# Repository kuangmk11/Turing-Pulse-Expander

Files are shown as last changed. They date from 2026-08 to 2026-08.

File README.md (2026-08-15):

# Turing Pulse Expander — archive

> **This repository is an archive.** The finished work has moved out into its own
> repositories; what remains here is upstream material and the studies that were
> superseded along the way.

| Live work | |
|---|---|
| **[Doubleplus_Pulses](https://github.com/kuangmk11/Doubleplus_Pulses)** | **Pulses Plus** — the built and tested hardware. KiCad schematic, PCB, panel v4, BOM, gerbers, and the full design write-up. CC BY-NC-SA 4.0. |
| **[Doubleplus_Pulses_VCV](https://github.com/kuangmk11/Doubleplus_Pulses_VCV)** | The VCV Rack 2 port of the same module. GPL-3.0-or-later. |

Both were extracted with `git subtree split`, so their commit history came with
them. Their files remain in this repository's history too, up to the commit that
removed them — nothing was rewritten here.

---

## What Pulses Plus is

A performance-oriented gate router for the Music Thing Turing Machine: eight pulse
channels, each switchable to one of two merge buses or off, with each bus computing
the OR or the AND of whatever is routed to it, chosen live from the panel. It
generalises the stock Pulses expander's four hard-wired AND outputs into any subset
of the eight bits, OR'd or AND'd, by hand.

See [Doubleplus_Pulses](https://github.com/kuangmk11/Doubleplus_Pulses) for the
design and the write-up.

---

## What's left here

### Upstream: Rev 2 Turing Pulse Expander

This repository is a fork of
[TomWhitwell/Turing-Pulse-Expander](https://github.com/TomWhitwell/Turing-Pulse-Expander),
and keeps that link deliberately — it is the right home for Tom Whitwell's files.

- `Hardware/pulses_rev2.brd`, `Hardware/pulses_rev2.sch` — the original Eagle design
- `Collateral/` — his gerbers, panel artwork and schematic PDF

The Rev 2 expander is a slightly updated Turing Machine Pulse Expander with more
outputs — SMD, but still an easy build. Its BOM:

- 1 × 4081 Quad AND Gate, SO14 package
- 11 × 3 mm LEDs
- 11 × 1k resistors, 1206
- 11 × 2k resistors, 1206 (LED protection — change the value for high-intensity LEDs)
- 11 × [Thonkiconn](https://www.thonk.co.uk/shop/thonkiconn-3-5mm-jack-sockets-x50/) sockets
- 1 × 16-pin header 2×8 (e.g. Mouser 649-67997-216HLF)
- 1 × ribbon cable

### Dead ends and studies

- `Docs/build_*.py`, `kfp.py`, `ksym.py`, `panel_geom.py`, `patch_footprints.py` —
  the generator scripts that built the earlier `pulses_plus` board from source.
  The finished module took a different route: it carries a single, much smaller
  `tools/build_panel.py` that regenerates only panel artwork from the v1 panel.
- `Docs/panel/` — two early panel layout studies (`v1-two-column-grid.html`,
  `v2-zigzag.html`) and the notes comparing them. The zig-zag won and became the
  shipped panel.
- `Hardware/pulses_plus/` — the superseded full-size design that preceded the
  sub-miniature-toggle version. **Present on disk but never committed**; it is
  gitignored and always has been, so it does not exist in this repository's
  history and will not appear in a fresh clone.
- Assorted scratch material at the repository root (`Chat.txt`, `path30.svg`,
  panel artwork exports) — likewise gitignored, on disk only.

---

## Licence

**Tom Whitwell's Rev 2 expander** — `Hardware/pulses_rev2.brd`, `Hardware/pulses_rev2.sch`
and `Collateral/` — is his, inherited by forking
[TomWhitwell/Turing-Pulse-Expander](https://github.com/TomWhitwell/Turing-Pulse-Expander).
Nothing here grants rights over it. For context, the parent
[Turing Machine](https://github.com/TomWhitwell/TuringMachine) project's README states
[CC-BY-SA 3.0](https://creativecommons.org/licenses/by-sa/3.0/), but that is not
stated in the expander repository itself.

**The Pulses Plus studies** in `Docs/` are Missing Mile Modular's, under
[CC BY-NC-SA 4.0](https://creativecommons.org/licenses/by-nc-sa/4.0/) — the same
terms as the finished hardware.

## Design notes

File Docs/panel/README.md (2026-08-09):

# Panel layout iterations — Pulses Plus

Open the HTML files in a browser. Both draw the panel **to scale** (1 HP = 5.08 mm, 3U = 128.5 mm).

| File | Layout | Outcome |
|---|---|---|
| `v1-two-column-grid.html` | Toggles in a 2 × 4 grid, LEDs outboard | Superseded. Needed 8–12 HP. |
| `v2-zigzag.html` | Toggles alternating left/right of a centred LED column | **Current.** Fits 6 HP. |

## What each iteration established

**v1** proved the constraint that shapes everything else: a 3U panel has ~110 mm of usable height,
and a single column of ten toggles plus three jacks needs ~160 mm. There is no single-column version
of this module — the channels have to be split across two columns somehow.

**v2** found the better way to split them. Staggering the toggles left and right of a centred LED
column means vertically adjacent toggles are never on the same side, so **row pitch no longer has to
clear a toggle nut**. That decoupling is what buys 6 HP: same-side toggles end up 17.25 mm apart —
more finger room than v1's 10 HP grid had — in half the width.

With the bus outputs moved to the bottom (jacks at the very bottom, vertical-throw mode toggles
above them, bus LEDs above those), the channel zigzag stretches to fill the panel at an 8.625 mm row
pitch. That pitch isn't chosen — it's back-solved from landing the EXT jack one full zigzag step
below channel 8 while still clearing the bus LEDs.

Each channel LED rides 2.5 mm above its toggle's row with the channel number silkscreened directly
beneath it, which is what makes the alternation readable at a glance.

## The remaining constraint is horizontal, and the nut decides it

Switch selected: **Adam Tech SW-T2-4X-E-A2-MA2** — DPDT ON-OFF-ON, M6 × 0.75 bushing, PCB vertical.
DPDT is an electrical requirement, not a preference; a single-pole switch leaks the AND bus into the
OR bus through the unselected throw (see the topology note in
[`../pulses-plus-design.md`](../pulses-plus-design.md)).

That's a *miniature* bushing, not sub-miniature, so at 6 HP there is only **1.6 mm of panel between
each toggle nut and its LED hole** — buildable, but only with bare 3 mm LEDs in bare holes, no bezels
or holders. Behind the panel, the 13.2 mm body against a 14.5 mm column pitch leaves 1.3 mm between
adjacent switch bodies. Tight, but it clears.

**Panel gets the ø6.00 mm bushing hole only — no anti-rotation key hole.** Adam Tech's recommended
cut-out puts a ø2.40 mm key hole 6.40 mm from the bushing centre, which would overlap the channel
LED hole outright. The six solder pins prevent rotation once the switch is PCB-mounted, so the key
hole is unnecessary. Don't copy the datasheet cut-out into the panel DXF.

**The nut turned out not to be a gate — 6 HP works.** Worst plausible M6 toggle nut (11 mm across
corners) still clears the LED hole by 0.52 mm; a typical 9.2 mm nut clears by 1.42 mm. It never
overlaps. So the nut only decides how tight the panel *looks*, and whether an LED bezel is possible
(it isn't). 6 HP vs 8 HP is now a rack-space call, not an engineering one — 8 HP takes that gap to
6.3 mm and leaves room for real legends.

## The panel as a PCB

`../build_panel.py` generates the panel as a standalone board — holes and silkscreen only, no
components — to `../../Hardware/pulses_plus/pulses_plus_panel_{6,8}hp.kicad_pcb`. Switches and jacks
mount on the main board behind and their own nuts hold the panel on. Artwork is on F.SilkS with the
F side facing the player.

Toggle columns are pinned to the panel **edge** rather than the centreline, so extra HP goes into the
toggle-to-LED gap — the only place it's needed.

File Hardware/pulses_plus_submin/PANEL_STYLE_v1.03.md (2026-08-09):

# Front panel style

**Version 1.03.**

House style for my module front panels — what marks go on them, what each one means, and
where it sits. It is a drawing spec, not a program: a panel is in the style if it satisfies
the rules below, whether it was generated or drawn by hand.

The look is borrowed from RYO's *Altered States* (`reference.jpg`) and is deliberately
PCB-native: single-weight plotter lettering, connections routed the way a trace is routed,
and dots where a silkscreen would have vias. Printed as white silkscreen on black
soldermask.

The rules were fitted to a set of eleven generated Kassutronics panels. That is where the
numbers come from, and why some are stated to the hundredth of a millimetre — they were
measured off production artwork, not chosen.

## Two ways to draw one

**Generated.** One `<stem>.layout.json` per panel says what its controls are and how they
relate; every mark comes from a single style library, so changing a number there changes
every panel at once.

```sh
tools/build_styled_panels.sh            # every finished layout
tools/build_styled_panels.sh Slope      # just the ones whose path matches
```

Outputs land beside each source as `<stem>.styled.{panel.json,kicad_pcb,svg}`, leaving the
PDF-derived conversions untouched.

**Drawn.** A hand-written SVG at 1:1, one user unit = 1 mm — `docs/v3-panel.svg` in this
repo is one. Nothing below needs a generator; the tokens are just numbers.

Where a rule is easier to state as tool behaviour ("the composer refuses to write if…"), it
is stated here as the rule being enforced. A generator should enforce it. A hand drawing has
to be checked.

## The one rule that is not negotiable

**Control hole positions are inherited, never computed.**

A panel serving a board that already exists — a port of someone else's module, or a revision
like this adder's v3 — takes its hole positions from that board and may not move them. A
panel whose holes move stops fitting its main board. v3 reassigns hole *diameters* between
6 mm jack and 5 mm toggle and keeps all sixteen positions from the built v2.2 panel.

On a genuinely new board the positions are fitted once, when the board is laid out, and are
inherited from then on.

Either way, **every hole is accounted for**, so a jack cannot silently vanish because a
layout forgot it.

Mounting holes are the exception: they meet the rails, not the module's own board, so they
are regenerated (below).

## Tokens

Every value is one number in one place. A generator holds them together; a hand drawing
copies them from here.

| | value | |
|---|---|---|
| `LINE_W` / `RULE_W` | 0.25 / 0.20 mm | wires, brackets, rings / centre divider |
| `LABEL_SIZE` / `PITCH_LABEL` | 2.0 / 2.2 mm | control labels |
| `SMALL_SIZE` / `PITCH_SMALL` | 1.6 / 1.7 mm | crowded rows, notes, bracket labels |
| `TITLE_SIZE` / `PITCH_TITLE` | 3.2 / 3.4 mm | module name |
| `LOGO_SIZE` / `PITCH_LOGO` | 1.3 / 1.45 mm | wordmark |
| `TRAVEL_DOT_D` / `TRAVEL_END_D` | 0.9 / 1.4 mm | knob travel marks |
| `DOT_D` | 0.6 mm | star-field, when used at all |
| `RING_GAP` | 1.2 mm | output ring stands off the hole edge |
| `EDGE_MARGIN` | 0.6 mm | no silkscreen closer than this to the cut |

**Tracking.** The reference's lettering is monospaced and widely tracked; stroke fonts
(Newstroke, and most plotter faces) are proportional, and KiCad has no letter-spacing
setting. So text is set **one character at a time** on a fixed pitch, each centred in its
own cell. Everything is uppercase.

## Marks and what they mean

**Knob travel — a dotted arc.** Eleven dots every 30°, at every position except +90°; the
gap at the bottom is where the label goes and the two dots either side of it, at +120° and
+60°, are the ends of travel and are drawn heavier. These positions are not invented: they
are measured off the starbursts on the ASR, both Attenumix panels and the Avalanche VCO,
which all draw the same 300° pot. The radius sits inside the band that artwork occupies —
3.75 to 8.06 mm on a 7.5 mm pot — so the marks stay visible with a knob fitted.

```
        ·  ·  ·               11 dots, r = hole_r + 3.45
      ·         ·
    ·     (O)     ·           hole
      ·         ·
     ●           ●            heavy: ends of travel, +120 / +60
          FOLD                the 30 deg gap at +90
```

- a **small** knob pulls the radius in for tightly spaced rows (Slope's Shape/Sustain sit on
  13.3 mm centres);
- a **big** knob draws **two** concentric rings, for an oversized main knob whose starburst
  runs out to 18.5 mm rather than 8.5 — the 3340 and KS-20 Frequency, the Ladder Filter, the
  Wavefolder's Fold;
- **bipolar** adds a heavier dot at 12 o'clock for the centre detent, and sets `-` / `+`
  outside the travel ends;
- **named ends** do the same with words, for the KS-20's `LP` / `HP` Mode.

**A ring means signal leaves here.** Every jack is an input or an output, and an output
draws the ring. Keeping it the only closed circle on a panel is what lets direction read at
a glance — which is also why nothing else may be a closed circle.

**A bracket groups one direction only.** It says *these belong together*, so enclosing an
input and an output in one misstates the signal flow. A bracket that mixes directions is an
error, not a judgement call. Labels sit in gaps in the bracket's own top edge. An output row
inside a bracket does not also get rings — the bracket already says it.

**An outline groups by function, not direction.** A plain rounded box at the lighter rule
weight, drawn round everything belonging to one section — the Quantizer's two channels, each
of which necessarily has both an input and an output, so the bracket's one-direction rule
does not apply. Where a bracket labels a row in its own top edge and must not mix
directions, an outline just says *this lot is one thing*.

**A span is one shared label** over a bar covering the controls it names, with a tick turning
down at each end — the 3340's two V/Oct inputs get one word, not the same word twice.

**A wire is a connection**, routed with one knee using only 0°, 90° and 45° segments,
stopping short of what it joins and breaking around any label it passes under. Routing does
**not** avoid obstacles: check that a wire does not cross a control, or drop it.

## Layout

**A name goes below the thing it names.** Every jack, every LED, every pot, every switch —
one rule, no exceptions, measured from whatever is drawn around the hole (a pot's travel
ring, an output's ring) and not from the hole itself. A panel where some names sit above
and some below makes the reader work out which each time.

**A mark that means a position goes where that position is.** Travel dots ring the pot,
`+` and `−` straddle a toggle, selector values stack beside the throws they select. These
are not names and the rule above does not apply to them — a `+` under a switch is wrong
however consistent it looks.

That leaves the case where a switch needs a name *and* position marks. The name takes the
baseline of the topmost position mark, off to one side of it. It must not sit directly
outboard of a `+` on the same baseline, or the two read as one word — `+OCTAVE`.

Three things adjust themselves and should not be fought:

- a row whose labels would collide, or would need shoving back inside the board, drops to the
  small size **as a whole row**;
- every label in a row is snapped to one baseline, so a ringed output does not sit 1.2 mm
  below its plain neighbours;
- the title shrinks to fit the clear span between the mounting slots.

When a row still needs help, in the order to reach for it: the small size, a larger label
gap, the label moved to a named direction, the label placed at an explicit `[x, y]`. An
explicit title height and size exist for panels where a control near the top leaves only
~2 mm of clear band.

## Mounting

Regenerated to one rule, as 6.4 × 3.2 mm obround slots milled on Edge.Cuts — horizontal, so
a module can slide ±1.6 mm to meet its neighbours.

| | |
|---|---|
| vertical | centre 3.0 mm from the top and bottom edges |
| horizontal | centre 7.5 mm in from the edge; the opposite column steps out by N × 5.08 mm |
| **> 6 HP** | both columns, 4 slots — 8 HP at 7.5 / 32.9, 10 HP at 7.5 / 43.06 |
| **≤ 6 HP** | one slot top and bottom on **opposite corners**, top right and bottom left. One screw per rail is enough at that width, and diagonal placement stops the module pivoting. |

The 7.5 mm inset is the datum and the grid steps out from it, so the far margin lands at
7.26–7.44 rather than exactly 7.5. That is the way round that matters: the grid is what the
rail is drilled to.

Where the panel is inherited (above), its existing mounting holes win — a v2.2-era panel with
round Ø3.2 holes keeps them.

## The wordmark

**The mark names who designed the module.**

| the design is | the panel says |
|---|---|
| mine, original | `MISSING MILE MODULAR` — `MMM` where the width does not allow it |
| a port or revision of someone else's | that maker's name — `KASSUTRONICS`, `KT` on 4 HP |
| this precision adder | `508`, which is what the built v2.2 panel carries, kept for continuity |

Whatever the word, it is letterspaced inside a plain two-lead component frame — the same
schematic-fragment idea as RYO's, a different part. It sits at `height − 7.0`, above the
mounting line, because a 6.4 mm slot leaves only 17.8 mm between the bottom pair and a full
wordmark needs 19.0. At 4 HP the bottom margin has only ~7 mm of clear width, which is what
the short forms are for.

## The back of the panel

The front says who designed the module in three letters. The back says it in full, and
says what may be done with the design — it is the one surface with room, and nothing on
it competes with the artwork.

Two things go there, both on `B.SilkS`, uppercase and letterspaced like everything else,
at `SMALL_SIZE` or just under:

| | |
|---|---|
| credit | `DESIGNED BY MISSING MILE MODULAR <year>` — the year the artwork was cut, not the year the circuit was designed |
| licence | the short form alone, e.g. `CC-BY-SA`. No URL: it will not be read off the back of a module, and it costs a line |

Wrap the credit rather than shrink it. Below about 1.2 mm the strokes start to fill in on
black soldermask, so a long name becomes two lines at the small size, never one line at a
size chosen to fit.

**Placement is whatever the holes leave.** Control holes go clean through, so the back has
no artwork of its own to work around and no keepouts but the holes themselves. Find the
clear bands between hole rows and set the type in those; a band needs the line height plus
`EDGE_MARGIN` top and bottom. There is no fixed position, because no two panels leave the
same gaps.

**Back text is emitted right-to-left.** KiCad mirrors each glyph about its own anchor, so
a run of cells laid out left-to-right in board coordinates reads backwards once the board
is turned over. Since the tracking rule already sets every character in its own cell, the
fix is to reverse the cell order — the string is unchanged, the cells are dealt out from
the right. A generator does this; a hand drawing has to be checked against a mirrored
render, not against the editor.

## Screw holes

3.4 mm holes fix the board behind the panel. They are drilled and then ignored: they need no
layout entry, take no label and get no marks. Mounting slots are treated the same way.

## The star-field

Off. The reference's scatter reads as texture because it covers a whole panel edge to edge;
here, once the keepouts around holes, wires, brackets and type have taken their share, there
is nothing left but orphans — measured, 15 of 17 survivors on Slope had no near neighbour,
and the ASR had none at all. An orphan dot reads as fab dirt. The travel rings already carry
the polar-dot language.

It stays available, and a panel that turns out to have real open space can opt back in.

## Per-module cases

Rules that exist for one panel and are recorded so they are not mistaken for house style.

**The Kassutronics Quantizer's glyphs.** Its shift layer is iconographic, and those icons are
what its user manual teaches, so they are redrawn rather than replaced with words — twelve of
them, each built in a local box running -1..1 from the same strokes and arcs as everything
else and scaled on placement:

| button | glyph | function |
|---|---|---|
| 0 | `gate_length` | gate length — a crotchet and a minim, a short note and a long one |
| 1 | `rotate` | rotate menu |
| 2 / 3 | `transpose_both` / `transpose_one` | transpose |
| 4 / 5 | `offset_both` / `offset_one` | offset |
| 6 | `keyboard` | keyboard mode |
| 7 | `legato` | legato — two crotchets under a slur |
| 8 | `gear` | settings |
| 9 | `tau` | gate length |
| 10 / 11 | `cv_a` / `cv_b` | CV A / CV B menus |

The "both channels" glyphs carry two marks where the "one channel" ones carry one — the
distinction the original draws, and the one the manual describes. `tau` is drawn rather than
set, so it cannot depend on the stroke font carrying Greek.

**The keyboard ring inverts.** The original fills the five *black* keys as wedges on a white
panel. Straight onto black soldermask that reading breaks, so the seven **white** keys are
filled instead and the black keys are left as bare panel — same keyboard, same contrast,
opposite ink. Adjacent white keys (E–F, B–C) merge into one shape, as on a real keyboard.
Each wedge subtracts its own scale button's hole with clearance rather than printing over it.
The numbers moved outside the keyboard ring to make room, and **3 and 9 are omitted** — they
sit dead on the panel edges, exactly as on the original.

**Pulses Plus, and what an 8 HP panel of nothing but toggles forces.**

*The title wraps.* `DOUBLEPLUS++PULSES` is eighteen characters, which at `PITCH_TITLE`
wants 61 mm on a 40 mm panel. Shrinking it to fit puts the title at label size, where it
stops reading as a title at all. It breaks to two lines at the full `TITLE_SIZE` instead,
centred in the band between the top mounting holes and the first LED. Prefer two full-size
lines to one shrunken one whenever the clear band is tall enough.

*The bus indicator LEDs take no label.* Each bus is a column — indicator, mode switch,
output jack, in line — and the jack at the foot of the column is labelled `A` or `B`. A
letter on the LED as well would print the same word twice in 25 mm. This is a real
exception to "every LED gets a name", allowed only because the column reads as one thing
and the name is directly below it.

*`AND` / `MUTE` / `OR` is one stack between two switches.* Both mode switches carry the
same three positions, and the centre position cannot be marked where it is — that is the
hole. So the three words sit in the centre column, on the switches' own baselines, serving
both. Position marks normally go beside the control they belong to; here they go between
two identical controls, which is the only reading that does not double them.

*The throw marks do not.* All eight routing toggles throw on the X axis and are wired
identically, so `A`/`B` could have been said once. It is said on every switch, because it
is a position mark and not a name: the panel has to answer "which way is bus A" at the
switch the hand is on, not at the top of the column.

## Checking a panel

For a generated panel, start from a stub with every hole classified by diameter and each
label `TODO`; the build skips any layout still containing `TODO`.

```sh
python3 tools/panel_compose.py --stub documentation/Foo/Foo.panel.json
```

Then, in this order, however the panel was made:

1. **every control matched and every hole accounted for** — no unmatched control, no
   unaccounted hole;
2. **hole positions identical to the board's.** Compare against the drill file, not against
   the last drawing;
3. **no collisions.** For a KiCad panel, `kicad-cli pcb drc` reports **zero** violations —
   not "warnings only", since the keepouts are under our control and anything surviving is
   real. For a drawn panel, print at 100%, check the sheet measures what the drawing claims,
   and check clearance on anything unproven by an existing build;
4. **rasterise it and look at it.**

## Versioning

**Any change to this document increments the version by one hundredth** — v1.02 → v1.03 →
v1.04, and so on. There is no distinction between a typo and a new rule; every edit is a
bump.

Two things move together, and a change that touches only one of them is incomplete:

1. the version line at the top of this file;
2. the filename — `PANEL_STYLE_v1.03.md` → `PANEL_STYLE_v1.04.md`. Rename with `git mv` so
   the history follows the file.

Then update anything pointing at the old filename (`README.md`).

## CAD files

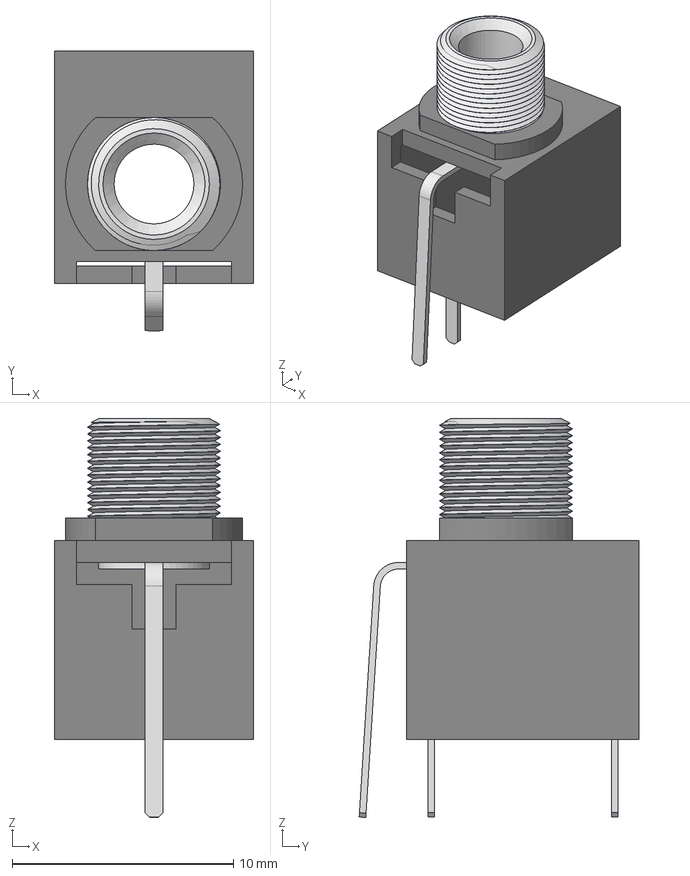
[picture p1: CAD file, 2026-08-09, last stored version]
Hardware/pulses_plus_submin/3d/PJ301M-12 Thonkiconn v0.2.stp
9.00 x 12.6 x 18.0 mm

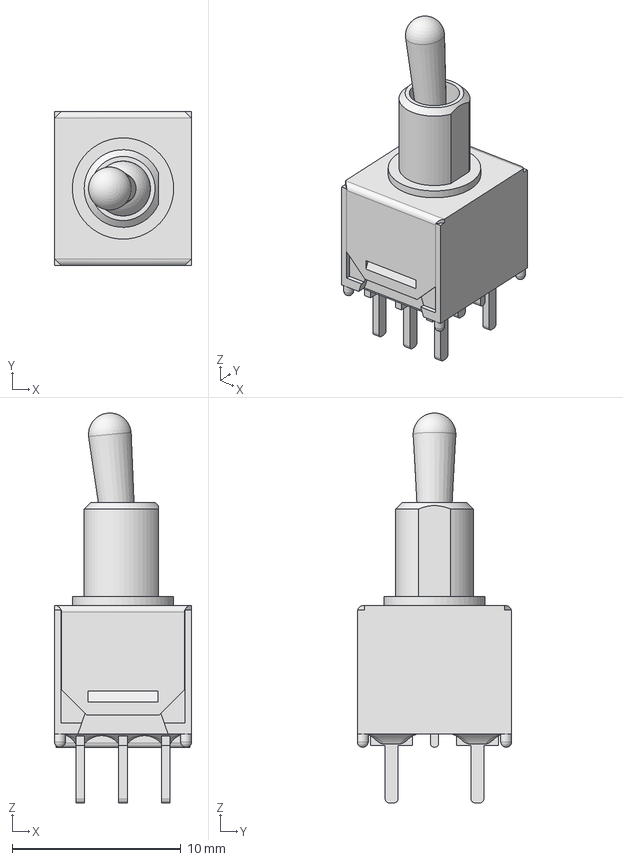
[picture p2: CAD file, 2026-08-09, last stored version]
Hardware/pulses_plus_submin/3d/200MDPxT2B1M2xE.stp
8.13 x 9.14 x 23.1 mm

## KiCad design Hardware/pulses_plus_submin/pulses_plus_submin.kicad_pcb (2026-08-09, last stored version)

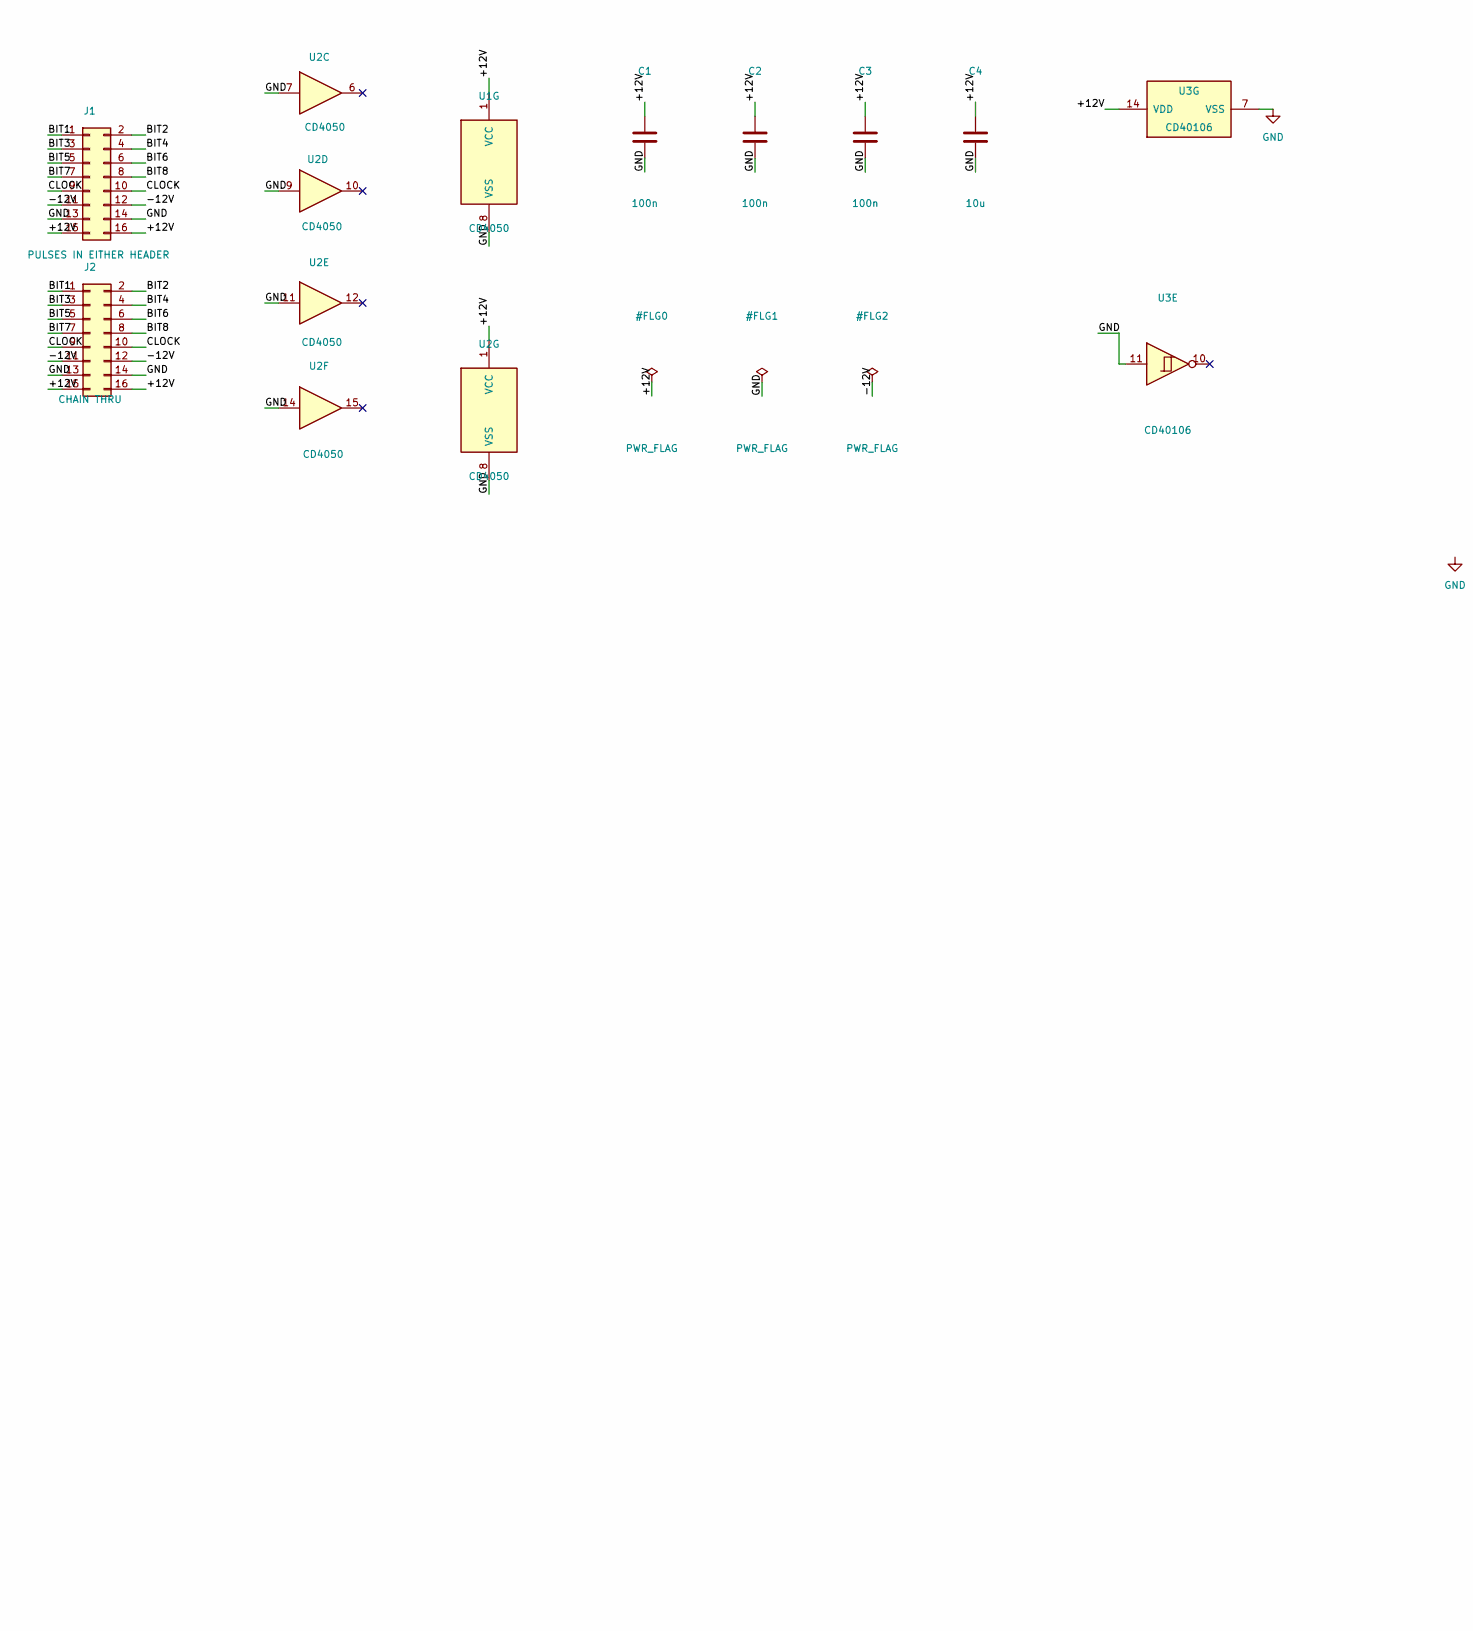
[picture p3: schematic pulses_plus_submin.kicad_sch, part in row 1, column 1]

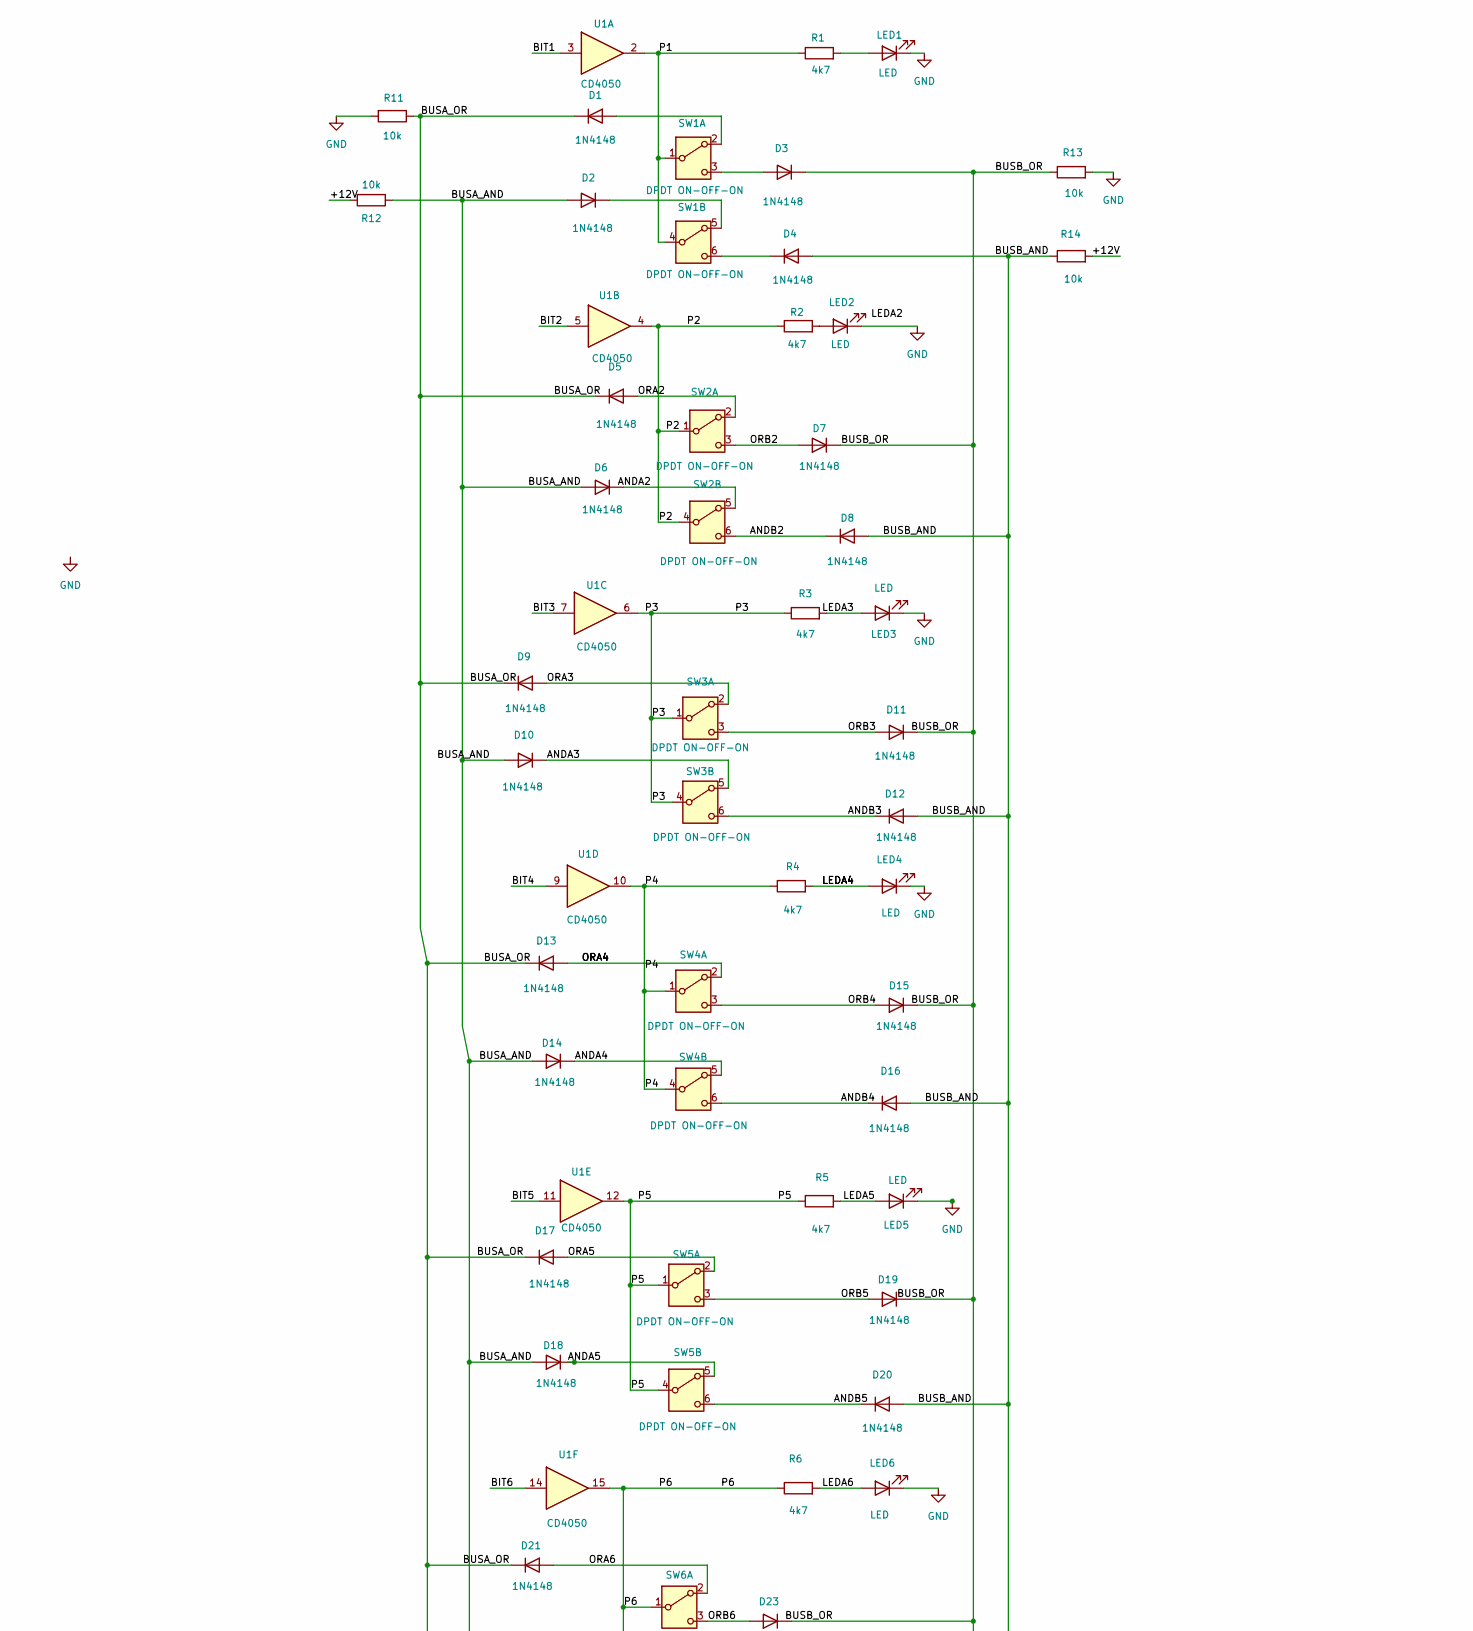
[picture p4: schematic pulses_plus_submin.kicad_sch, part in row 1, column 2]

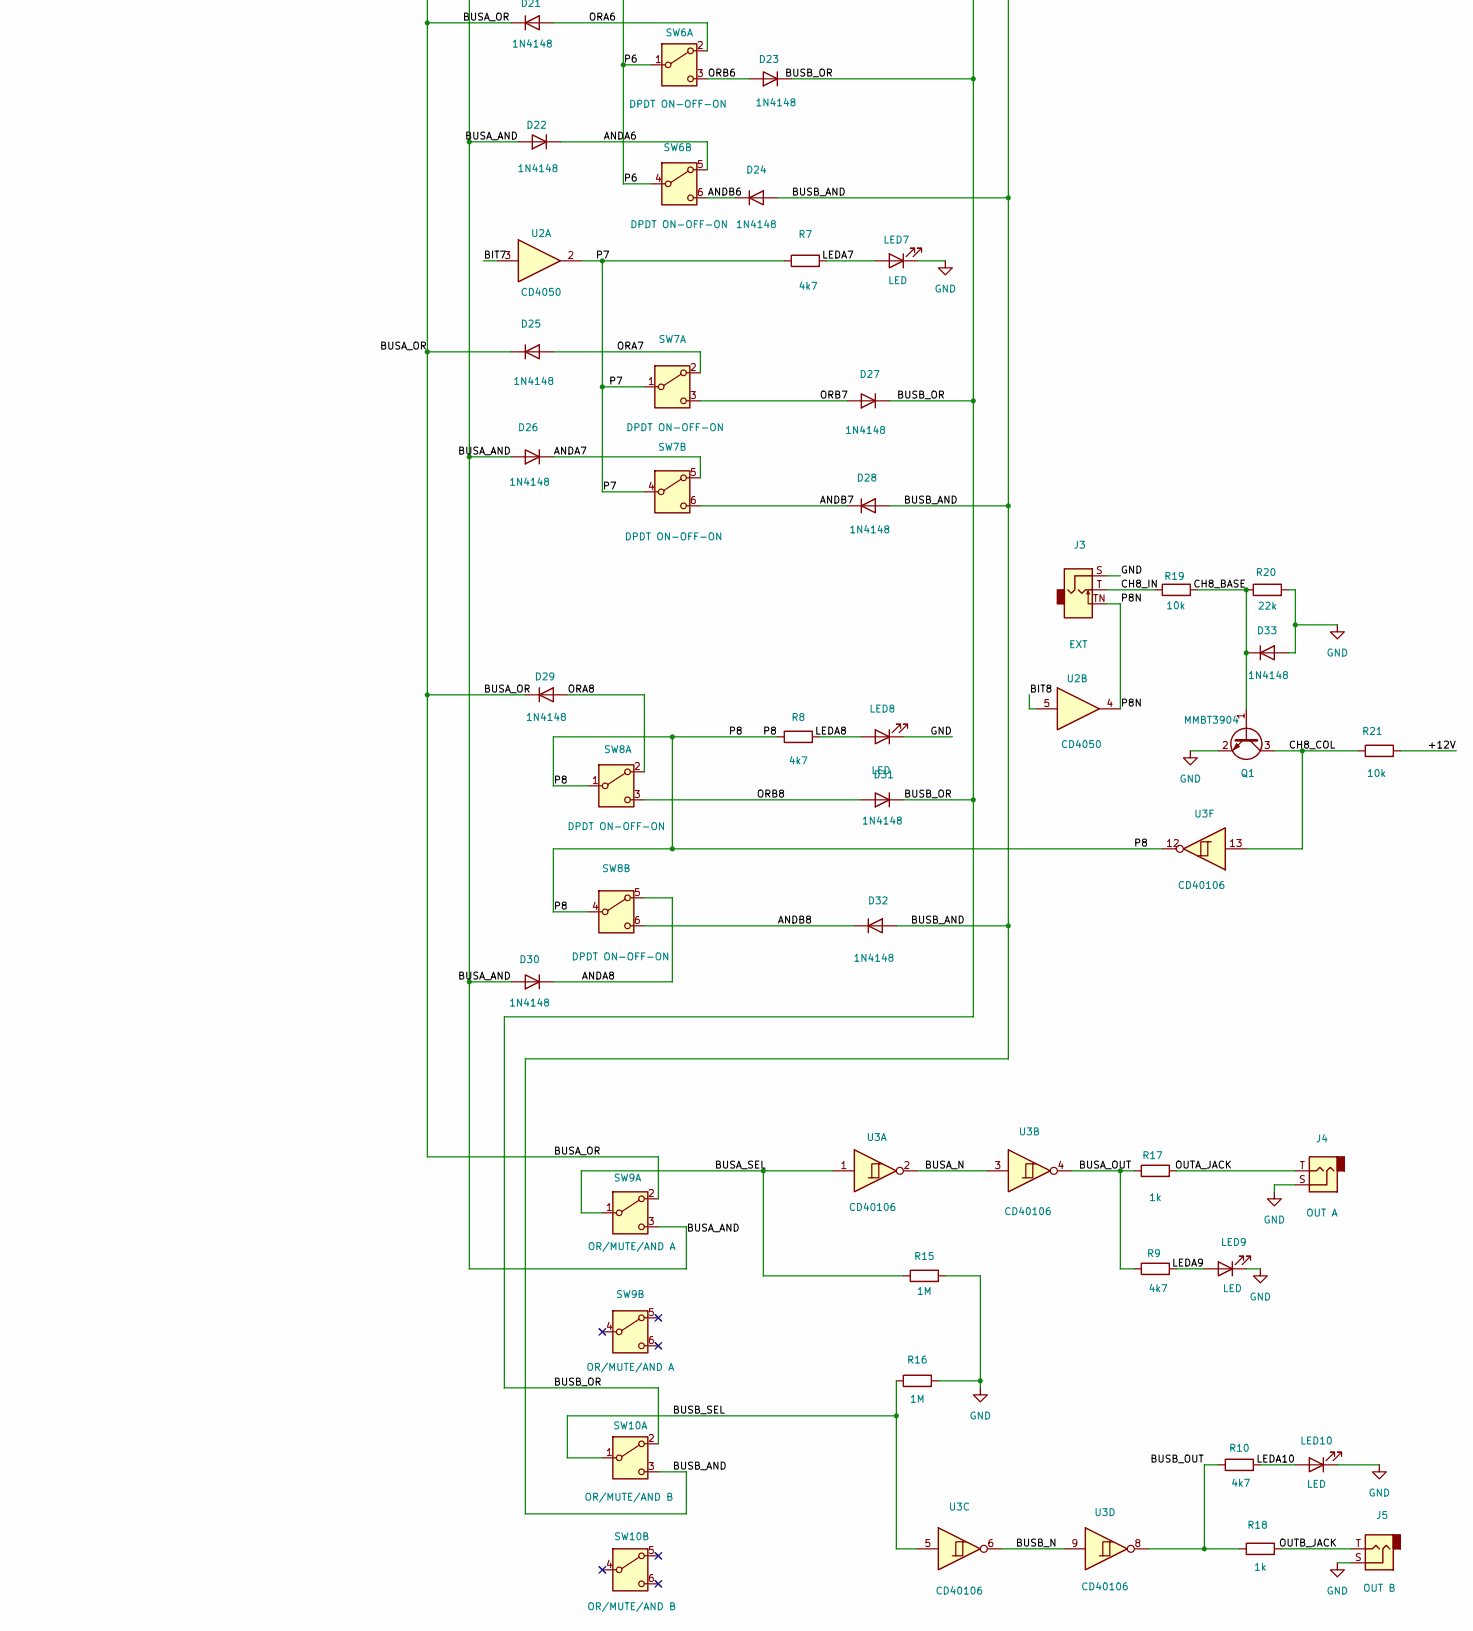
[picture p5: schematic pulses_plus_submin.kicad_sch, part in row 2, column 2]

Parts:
C1, C2, C3: 100n; C_1206_3216Metric_Pad1.33x1.80mm_HandSolder
C4: 10u; C_1206_3216Metric_Pad1.33x1.80mm_HandSolder
D1, D2, D3, D4, D5, D6, D7, D8, D9, D10, D11, D12, D13, D14, D15, D16, D17, D18, D19, D20, D21, D22, D23, D24, D25, D26, D27, D28, D29, D30, D31, D32, D33: 1N4148; D_SOD-123
J1: PULSES IN EITHER HEADER; IDC-Header_2x08_P2.54mm_Vertical
J2: CHAIN THRU; IDC-Header_2x08_P2.54mm_Vertical
J3: EXT; Thonkiconn_PJ301M
J4: OUT A; Thonkiconn_PJ301M
J5: OUT B; Thonkiconn_PJ301M
LED1, LED2, LED3, LED4, LED5, LED6, LED7, LED8, LED9, LED10: LED; LED_D3.0mm
Q1: MMBT3904; SOT-23
R1, R2, R3, R4, R5, R6, R7, R8, R9, R10: 4k7; R_1206_3216Metric_Pad1.30x1.75mm_HandSolder
R11, R12, R13, R14, R19, R21: 10k; R_1206_3216Metric_Pad1.30x1.75mm_HandSolder
R15, R16: 1M; R_1206_3216Metric_Pad1.30x1.75mm_HandSolder
R17, R18: 1k; R_1206_3216Metric_Pad1.30x1.75mm_HandSolder
R20: 22k; R_1206_3216Metric_Pad1.30x1.75mm_HandSolder
SW1, SW2, SW3, SW4, SW5, SW6, SW7, SW8: DPDT ON-OFF-ON; SW_200_MDP3_DPDT
SW9: OR/MUTE/AND A; SW_200_MDP3_DPDT
SW10: OR/MUTE/AND B; SW_200_MDP3_DPDT
U1, U2: CD4050; DIP-16_W7.62mm
U3: CD40106; DIP-14_W7.62mm

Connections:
/+12V: C1.1, C2.1, C3.1, C4.1, J1.15, J1.16, J2.15, J2.16, R12.2, R14.2, R21.2, U1.1 (VCC), U2.1 (VCC), U3.14 (VDD)
/-12V: J1.11, J1.12, J2.11, J2.12
/ANDA2: D6.1 (K), SW2.5 (B)
/ANDA3: D10.1 (K), SW3.5 (B)
/ANDA4: D14.1 (K), SW4.5 (B)
/ANDA5: D18.1 (K), SW5.5 (B)
/ANDA6: D22.1 (K), SW6.5 (B)
/ANDA7: D26.1 (K), SW7.5 (B)
/ANDA8: D30.1 (K), SW8.5 (B)
/ANDB2: D8.1 (K), SW2.6 (C)
/ANDB3: D12.1 (K), SW3.6 (C)
/ANDB4: D16.1 (K), SW4.6 (C)
/ANDB5: D20.1 (K), SW5.6 (C)
/ANDB6: D24.1 (K), SW6.6 (C)
/ANDB7: D28.1 (K), SW7.6 (C)
/ANDB8: D32.1 (K), SW8.6 (C)
/BIT1: J1.1, J2.1, U1.3
/BIT2: J1.2, J2.2, U1.5
/BIT3: J1.3, J2.3, U1.7
/BIT4: J1.4, J2.4, U1.9
/BIT5: J1.5, J2.5, U1.11
/BIT6: J1.6, J2.6, U1.14
/BIT7: J1.7, J2.7, U2.3
/BIT8: J1.8, J2.8, U2.5
/BUSA_AND: D2.2 (A), D6.2 (A), D10.2 (A), D14.2 (A), D18.2 (A), D22.2 (A), D26.2 (A), D30.2 (A), R12.1, SW9.3 (C)
/BUSA_N: U3.2, U3.3
/BUSA_OR: D1.1 (K), D5.1 (K), D9.1 (K), D13.1 (K), D17.1 (K), D21.1 (K), D25.1 (K), D29.1 (K), R11.1, SW9.2 (B)
/BUSA_OUT: R9.1, R17.1, U3.4
/BUSA_SEL: R15.1, SW9.1 (A), U3.1
/BUSB_AND: D4.2 (A), D8.2 (A), D12.2 (A), D16.2 (A), D20.2 (A), D24.2 (A), D28.2 (A), D32.2 (A), R14.1, SW10.3 (C)
/BUSB_N: U3.6, U3.9
/BUSB_OR: D3.1 (K), D7.1 (K), D11.1 (K), D15.1 (K), D19.1 (K), D23.1 (K), D27.1 (K), D31.1 (K), R13.1, SW10.2 (B)
/BUSB_OUT: R10.1, R18.1, U3.8
/BUSB_SEL: R16.1, SW10.1 (A), U3.5
/CH8_BASE: D33.1 (K), Q1.1 (B), R19.2, R20.1
/CH8_COL: Q1.3 (C), R21.1, U3.13
/CH8_IN: J3.T, R19.1
/CLOCK: J1.9, J1.10, J2.9, J2.10
/LEDA3: LED3.2 (A), R3.2
/LEDA5: LED5.2 (A), R5.2
/LEDA6: LED6.2 (A), R6.2
/LEDA7: LED7.2 (A), R7.2
/LEDA8: LED8.2 (A), R8.2
/LEDA9: LED9.2 (A), R9.2
/LEDA10: LED10.2 (A), R10.2
/ORA2: D5.2 (A), SW2.2 (B)
/ORA3: D9.2 (A), SW3.2 (B)
/ORA5: D17.2 (A), SW5.2 (B)
/ORA6: D21.2 (A), SW6.2 (B)
/ORA7: D25.2 (A), SW7.2 (B)
/ORA8: D29.2 (A), SW8.2 (B)
/ORB2: D7.2 (A), SW2.3 (C)
/ORB3: D11.2 (A), SW3.3 (C)
/ORB4: D15.2 (A), SW4.3 (C)
/ORB5: D19.2 (A), SW5.3 (C)
/ORB6: D23.2 (A), SW6.3 (C)
/ORB7: D27.2 (A), SW7.3 (C)
/ORB8: D31.2 (A), SW8.3 (C)
/OUTA_JACK: J4.T, R17.2
/OUTB_JACK: J5.T, R18.2
/P1: R1.1, SW1.1 (A), SW1.4 (A), U1.2
/P2: R2.1, SW2.1 (A), SW2.4 (A), U1.4
/P3: R3.1, SW3.1 (A), SW3.4 (A), U1.6
/P4: R4.1, SW4.1 (A), SW4.4 (A), U1.10
/P5: R5.1, SW5.1 (A), SW5.4 (A), U1.12
/P6: R6.1, SW6.1 (A), SW6.4 (A), U1.15
/P7: R7.1, SW7.1 (A), SW7.4 (A), U2.2
/P8: R8.1, SW8.1 (A), SW8.4 (A), U3.12
/P8N: J3.TN, U2.4
GND: C1.2, C2.2, C3.2, C4.2, D33.2 (A), J1.13, J1.14, J2.13, J2.14, J3.S, J4.S, J5.S, LED1.1 (K), LED2.1 (K), LED3.1 (K), LED4.1 (K), LED5.1 (K), LED6.1 (K), LED7.1 (K), LED8.1 (K), LED9.1 (K), LED10.1 (K), Q1.2 (E), R11.2, R13.2, R15.2, R16.2, R20.2, U1.8 (VSS), U2.7, U2.8 (VSS), U2.9, U2.11, U2.14, U3.7 (VSS), U3.11
unnamed: D1.2 (A), SW1.2 (B)
unnamed: D2.1 (K), SW1.5 (B)
unnamed: D3.2 (A), SW1.3 (C)
unnamed: D4.1 (K), SW1.6 (C)
unnamed: D13.2 (A), SW4.2 (B)
unnamed: LED1.2 (A), R1.2
unnamed: LED2.2 (A), R2.2
unnamed: LED4.2 (A), R4.2

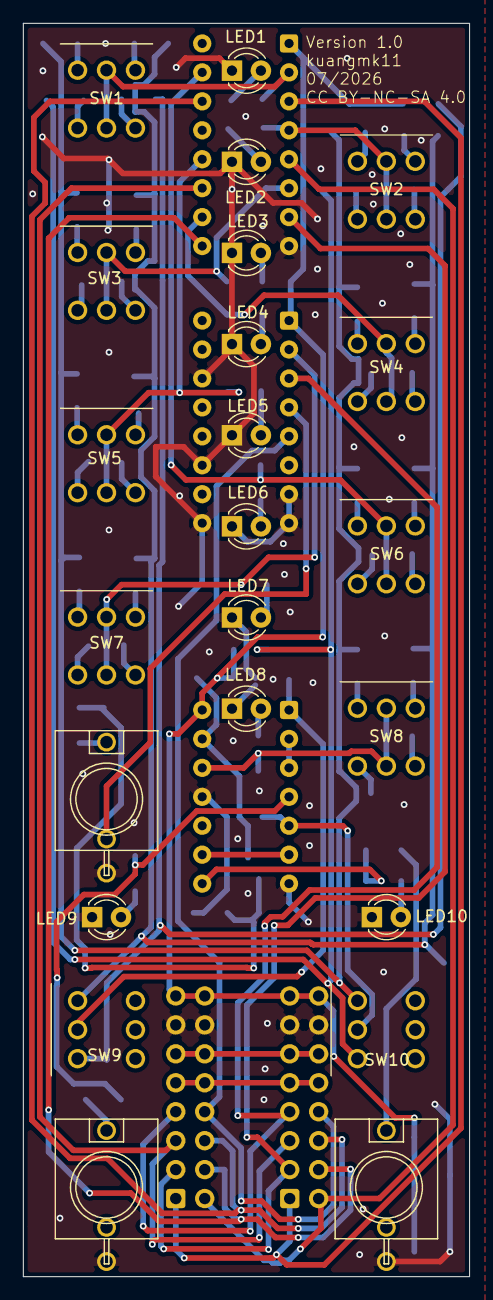
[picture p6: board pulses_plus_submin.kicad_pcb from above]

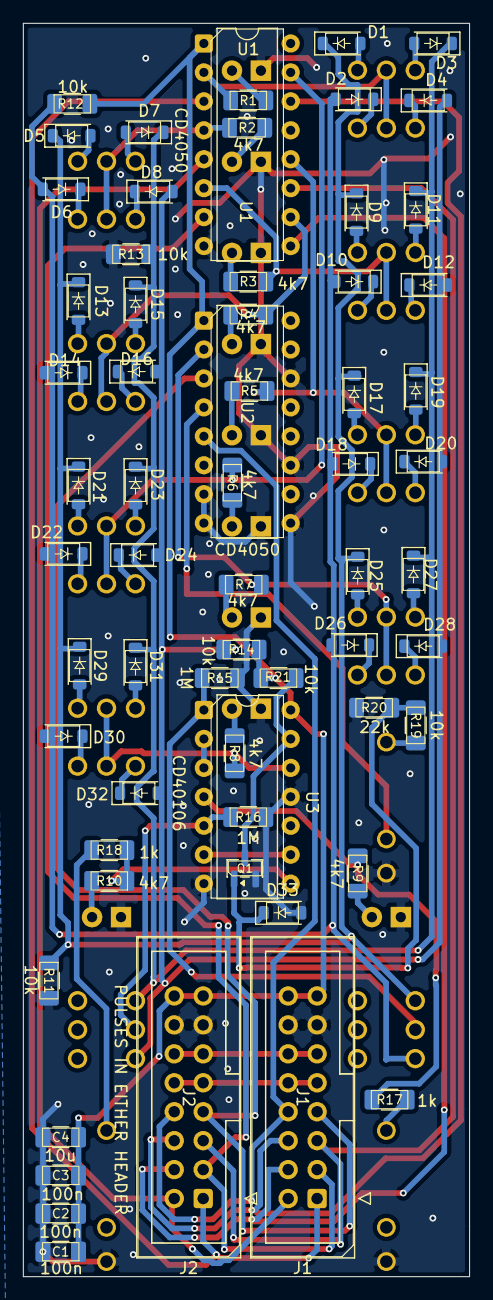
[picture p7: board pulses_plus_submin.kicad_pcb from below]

Board: 2 copper layers, 39.2 x 110.0 mm, 87 parts (64 on the bottom side), 78 nets.

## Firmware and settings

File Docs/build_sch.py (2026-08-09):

"""Generate pulses_plus.kicad_sch from the netlist in Docs/pulses-plus-design.md.

Connectivity is made with net labels placed on short stubs off each pin, rather than
routed wires. Electrically complete; visually it will want tidying by hand.
"""
import re, uuid, math, sys
import ksym

ROOT_UUID = "26a2b0ab-b556-45bb-8d80-d737de428f9e"   # from the existing empty sheet
PROJECT = "pulses_plus"
OUT = "/mnt/g/Documents/GitHub/Turing-Pulse-Expander/Hardware/pulses_plus/pulses_plus.kicad_sch"

U = lambda: str(uuid.uuid4())

# ---------------------------------------------------------------- netlist ----
# comp: ref -> (lib, sym, value, {unit: (x, y)}, {pin: net})
comps = {}

def add(ref, lib, sym, value, units, pins):
    comps[ref] = dict(lib=lib, sym=sym, value=value, units=units, pins=pins)

# --- ribbon headers: PULSES IN, and CHAIN THRU wired in parallel
HDR = {}
for p in range(1, 9):
    HDR[str(p)] = f"BIT{p}"
HDR["9"] = HDR["10"] = "CLOCK"
HDR["11"] = HDR["12"] = "-12V"
HDR["13"] = HDR["14"] = "GND"
HDR["15"] = HDR["16"] = "+12V"
add("J1", "Connector_Generic", "Conn_02x08_Odd_Even", "PULSES IN", {1: (30, 55)}, HDR)
add("J2", "Connector_Generic", "Conn_02x08_Odd_Even", "CHAIN THRU", {1: (75, 55)}, HDR)

# --- U1/U2 CD4050 input buffers.  units 1-6 = buffers, unit 7 = power.
# buffer unit -> (input pin, output pin)
BUF = {1: ("3", "2"), 2: ("5", "4"), 3: ("7", "6"),
       4: ("9", "10"), 5: ("11", "12"), 6: ("14", "15")}

u1_pins, u1_units = {"1": "+12V", "8": "GND"}, {7: (300, 40)}
for u, bit in zip(range(1, 7), range(1, 7)):          # BIT1..BIT6 -> P1..P6
    i, o = BUF[u]
    u1_pins[i] = f"BIT{bit}"
    u1_pins[o] = f"P{bit}"
    u1_units[u] = (115 + (u - 1) * 30, 40)
add("U1", "4xxx", "4050", "CD4050", u1_units, u1_pins)

u2_pins, u2_units = {"1": "+12V", "8": "GND"}, {7: (300, 85)}
NC = []                                                # no-connect points, filled later
for u in range(1, 7):
    i, o = BUF[u]
    u2_units[u] = (115 + (u - 1) * 30, 85)
    if u == 1:
        u2_pins[i], u2_pins[o] = "BIT7", "P7"
    elif u == 2:
        u2_pins[i], u2_pins[o] = "BIT8", "P8N"
    else:
        u2_pins[i] = "GND"                             # unused CMOS inputs must not float
        u2_pins[o] = None                              # spare output -> no-connect
add("U2", "4xxx", "4050", "CD4050", u2_units, u2_pins)

# --- channel 8 front end: EXT jack, transistor conditioner
add("J3", "Connector_Audio", "AudioJack2_SwitchT", "EXT",
    {1: (350, 55)}, {"T": "CH8_IN", "TN": "P8N", "S": "GND"})
add("R19", "Device", "R", "10k", {1: (385, 50)}, {"1": "CH8_IN", "2": "CH8_BASE"})
add("R20", "Device", "R", "22k", {1: (405, 65)}, {"1": "CH8_BASE", "2": "GND"})
add("D33", "Diode", "1N4148", "1N4148", {1: (425, 65)}, {"2": "GND", "1": "CH8_BASE"})
add("Q1", "Transistor_BJT", "2N3904", "2N3904",
    {1: (450, 55)}, {"2": "CH8_BASE", "1": "GND", "3": "CH8_COL"})
add("R21", "Device", "R", "10k", {1: (480, 40)}, {"1": "CH8_COL", "2": "+12V"})

# --- 8 channels: DPDT routing switch, 4 merge diodes, LED
# pole 1 (unit 1) carries the OR diodes, pole 2 (unit 2) the AND diodes.
# Splitting the poles is what stops the AND pullup leaking into the OR pulldown
# through an unselected throw.  A=common, B=throw A(bus A), C=throw B(bus B).
for n in range(1, 9):
    bx = 25 + (n - 1) * 63.5
    P = f"P{n}"
    add(f"SW{n}", "Switch", "SW_DPDT_x2", "DPDT ON-OFF-ON",
        {1: (bx, 150), 2: (bx + 30, 150)},
        {"1": P,  "2": f"ORA{n}",  "3": f"ORB{n}",
         "4": P,  "5": f"ANDA{n}", "6": f"ANDB{n}"})
    # 1N4148: pin 1 = K (cathode), pin 2 = A (anode)
    add(f"D{4*n-3}", "Diode", "1N4148", "1N4148",
        {1: (bx, 190)},      {"2": f"ORA{n}",  "1": "BUSA_OR"})
    add(f"D{4*n-1}", "Diode", "1N4148", "1N4148",
        {1: (bx, 212)},      {"2": f"ORB{n}",  "1": "BUSB_OR"})
    add(f"D{4*n-2}", "Diode", "1N4148", "1N4148",
        {1: (bx + 30, 190)}, {"2": "BUSA_AND", "1": f"ANDA{n}"})
    add(f"D{4*n}",   "Diode", "1N4148", "1N4148",
        {1: (bx + 30, 212)}, {"2": "BUSB_AND", "1": f"ANDB{n}"})
    # channel LED taps pre-switch, so it shows the channel firing however it is routed
    add(f"R{n}", "Device", "R", "4k7", {1: (bx + 52, 165)}, {"1": P, "2": f"LEDA{n}"})
    add(f"LED{n}", "Device", "LED", "LED", {1: (bx + 52, 192)},
        {"2": f"LEDA{n}", "1": "GND"})               # pin 2 = A, pin 1 = K

# --- bus pull resistors
add("R11", "Device", "R", "10k", {1: (30, 285)},  {"1": "BUSA_OR",  "2": "GND"})
add("R12", "Device", "R", "10k", {1: (50, 285)},  {"1": "BUSA_AND", "2": "+12V"})
add("R13", "Device", "R", "10k", {1: (70, 285)},  {"1": "BUSB_OR",  "2": "GND"})
add("R14", "Device", "R", "10k", {1: (90, 285)},  {"1": "BUSB_AND", "2": "+12V"})

# --- bus mode switches.  Same Adam Tech SW-T2-4X-E (DPDT ON-OFF-ON) as the routing
# switches, so the whole panel is one part number and one footprint.  Pole 2 is unused.
# Centre-off leaves the common floating and R15/R16 pull the Schmitt input low, so the
# centre position is a per-bus MUTE: OR / MUTE / AND.
add("SW9",  "Switch", "SW_DPDT_x2", "OR/MUTE/AND A", {1: (130, 285), 2: (130, 320)},
    {"1": "BUSA_SEL", "2": "BUSA_OR", "3": "BUSA_AND",
     "4": None, "5": None, "6": None})
add("SW10", "Switch", "SW_DPDT_x2", "OR/MUTE/AND B", {1: (170, 285), 2: (170, 320)},
    {"1": "BUSB_SEL", "2": "BUSB_OR", "3": "BUSB_AND",
     "4": None, "5": None, "6": None})
add("R15", "Device", "R", "1M", {1: (205, 285)}, {"1": "BUSA_SEL", "2": "GND"})
add("R16", "Device", "R", "1M", {1: (225, 285)}, {"1": "BUSB_SEL", "2": "GND"})

# --- U3 CD40106: 2 gates per bus (double inversion = buffer), 1 gate for channel 8
add("U3", "4xxx", "40106", "CD40106",
    {1: (260, 285), 2: (295, 285), 3: (330, 285),
     4: (365, 285), 5: (400, 285), 6: (435, 285), 7: (470, 285)},
    {"1": "BUSA_SEL", "2": "BUSA_N",              # gate A
     "3": "BUSA_N",   "4": "BUSA_OUT",            # gate B
     "5": "BUSB_SEL", "6": "BUSB_N",              # gate C
     "9": "BUSB_N",   "8": "BUSB_OUT",            # gate D
     "11": "GND",     "10": None,                 # gate E spare
     "13": "CH8_COL", "12": "P8",                 # gate F -> channel 8
     "7": "GND", "14": "+12V"})

# --- output stage
add("R17", "Device", "R", "1k", {1: (505, 285)}, {"1": "BUSA_OUT", "2": "OUTA_JACK"})
add("R18", "Device", "R", "1k", {1: (525, 285)}, {"1": "BUSB_OUT", "2": "OUTB_JACK"})
add("J4", "Connector_Audio", "AudioJack2", "OUT A", {1: (555, 285)},
    {"T": "OUTA_JACK", "S": "GND"})
add("J5", "Connector_Audio", "AudioJack2", "OUT B", {1: (590, 285)},
    {"T": "OUTB_JACK", "S": "GND"})
add("R9",  "Device", "R", "4k7", {1: (625, 280)}, {"1": "BUSA_OUT", "2": "LEDA9"})
add("LED9", "Device", "LED", "LED", {1: (625, 305)}, {"2": "LEDA9", "1": "GND"})
add("R10", "Device", "R", "4k7", {1: (650, 280)}, {"1": "BUSB_OUT", "2": "LEDA10"})
add("LED10", "Device", "LED", "LED", {1: (650, 305)}, {"2": "LEDA10", "1": "GND"})
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

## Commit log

2026-08-09 Add .gitignore and .gitattributes
    Scope the repo to the shipped work: pulses_plus_submin (the tested
    hardware) and pulses_plus_vcvrack (the Rack 2 port), plus their design
    docs. Everything else stays on disk but out of git -- the superseded
    pulses_plus tree, the pulses_rev2 KiCad import, editor/tool noise
    (.history, *-backups, __pycache__, *.kicad_prl) and unrelated material
    at the repo root. Drops the tracked set from 88M to ~5M.
    .gitattributes fixes a CRLF/LF mismatch: the previous commit stored
    LF-only blobs, so a WSL/Linux clone saw 34 untouched files as wholly
    rewritten. Normalisation is scoped to our own trees; the default is
    '* -text' so files inherited from upstream stay byte-identi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
2026-08-09 Make pulses_plus_submin footprint and 3D refs portable
    The project had two references that only resolved on the machine it was
    authored on:
    - Thonkiconn_PJ301M.kicad_mod pointed its 3D model at
    ${KIPRJMOD}/SW-T2-4E-B-A2-MA2/3D/..., a directory that does not exist.
    The model is actually in 3d/, so repoint it there.
    - pulses_plus_submin_panel.kicad_pcb placed 27 footprints from a "Panel"
    library that is in neither the project fp-lib-table nor the tree; it
    resolved from a KiCad global table locally, so the panel would not open
    on a fresh clone. Vendor its three footprints (Hole_3.2mm, Hole_4.95mm,
    Hole_6mm -- each a single NPTH circular pad) into
    pulses_plus_submin.pretty and re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
    [pulses_plus_submin_panel.kicad_pcb]
2026-08-09 Add v2 panel in house style, and PANEL_STYLE v1.03
    New front panel for pulses_plus_submin, drawn to PANEL_STYLE. Every hole
    position, the Edge.Cuts outline and the copper are inherited verbatim from
    the v1 panel -- tools/build_panel_v2.py reads v1 and regenerates only the
    silkscreen, so the style guide's one non-negotiable rule (hole positions are
    inherited, never computed) holds by construction rather than by check. All
    27 holes verified identical to v1.
    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
    [pulses_plus_submin_panel_v2.kicad_pcb]
2026-08-09 Ignore KiCad editor lock files
2026-08-09 Keep the NonCommercial clause: CC BY-NC-SA 4.0 on the panel back
    The v2 panel back read CC-BY-SA, which is a different licence from the
    CC BY-NC-SA 4.0 the v1 panel carries -- it would have permitted commercial
    builds of the module. Restores the NC clause and the version number.
    PANEL_STYLE goes to v1.04: the licence line now has to be the short form
    *with* its version, and says why the clause letters are not cosmetic.
    [pulses_plus_submin_panel_v2.kicad_pcb]
2026-08-09 v2 panel: standard mounting slots, copper decoration redrawn as silk
    Mounting is regenerated to the house rule instead of inherited. 8 HP is
    > 6 HP, so both columns and four 6.4 x 3.2 mm obround slots milled on
    Edge.Cuts, horizontal so the module can slide +/- 1.6 mm onto the rails.
    Centres sit 3.0 mm from the top and bottom edges; the 7.5 mm inset is the
    datum and the far column steps out 5 x 5.08 to 32.9, leaving a 7.26 mm
    margin on that side -- the grid is what the rail is drilled to, so that is
    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
    [pulses_plus_submin_panel_v2.kicad_pcb]
2026-08-09 new panel
    [pulses_plus_submin_panel-B_Cu.gbr, pulses_plus_submin_panel-B_Mask.gbr, pulses_plus_submin_panel-B_Paste.gbr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]
2026-08-09 README: pulses_plus_submin is the finished project, panel v4 is current
    Rewrites the README around the work in this fork rather than upstream's Rev 2
    board. Leads with pp.PNG, names Hardware/pulses_plus_submin as the built and
    tested hardware, and points at panel v4 as the current one. Adds a short
    account of how the module works -- the two-pole split that keeps an unselected
    bus from leaking, the OR/MUTE/AND mode stack, the normalled EXT jack -- plus
    key parts, how to regenerate the panel, the VCV Rack port, and how to read the
    panel's marks.
    Upstream's Rev 2 description and BOM are kept, under their own heading and
    credited to TomWhitwell/Turing-Pulse-Expander, since that board and its
    ge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
    [pulses_plus_submin_panel_v2.kicad_pcb, pulses_plus_submin_panel_v4.kicad_pcb]
2026-08-09 README: scope the licence to what each part actually covers
    The footer claimed CC BY-NC-SA 4.0 over the whole repository, which by
    forking also contains Tom Whitwell's Rev 2 board (Hardware/pulses_rev2.*,
    Collateral/). Those files are not ours to license.
    Splits it: Pulses Plus under CC BY-NC-SA 4.0, and the inherited Rev 2 files
    credited to him with the fact recorded that his repository states no licence
    at all -- checked against its tree, its full history, the GitHub API and its
    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
2026-08-15 Become an archive: Pulses Plus moves to its own repositories
    The finished module and its VCV Rack port were the only live work here, and both
    were buried under a fork of someone else's project. They are now standalone:
    pulses_plus_submin the hardware, CC BY-NC-SA 4.0
    pulses_plus_vcvrack the VCV Rack 2 port, GPL-3.0-or-later
    Both were extracted with `git subtree split`, so their history went with them.
    Nothing is rewritten here — their files stay in this repository's history up to
    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
    [200MDPxT2B1M2xE.stp, PJ301M-12 Thonkiconn v0.2.stp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]
2026-08-15 gitignore: untrack machine-local Claude settings; expand coverage
    .claude/settings.local.json was tracked and therefore published. It holds
    per-machine permission grants and absolute filesystem paths (/home/ono,
    /mnt/c/Users/...) — nothing secret, but nothing that belongs in a public
    repo either. Now ignored and untracked; the file stays on disk. It remains
    in this repository's history, which seemed not worth a rewrite for a
    permission allowlist.
    Adds a consistent baseline across the Missing Mile repos: machine-local
    Claude Code settings (.claude/*.local.json hold per-machine permission grants
    and absolute filesystem paths), KiCad autosave/lock/report/routing-exchange
    noise, editor direct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
